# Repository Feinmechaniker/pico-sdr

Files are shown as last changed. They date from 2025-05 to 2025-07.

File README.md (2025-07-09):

This repository holds files relevant to the PiCo Rx project - a design by Jon Dawson 
(see: https://101-things.readthedocs.io/en/latest/breadboard_radio.html ).
I adopted this wonderful idea from Jon to customize the hardware to my liking.

my current circuit diagram
diagram

current circuit board (Top-Side)

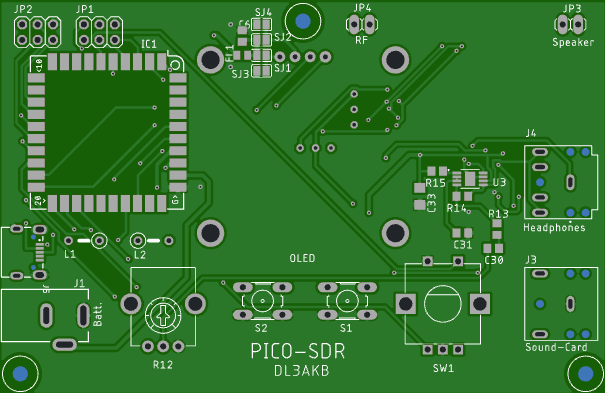
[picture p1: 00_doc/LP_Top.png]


current circuit board (Bottom-Side)

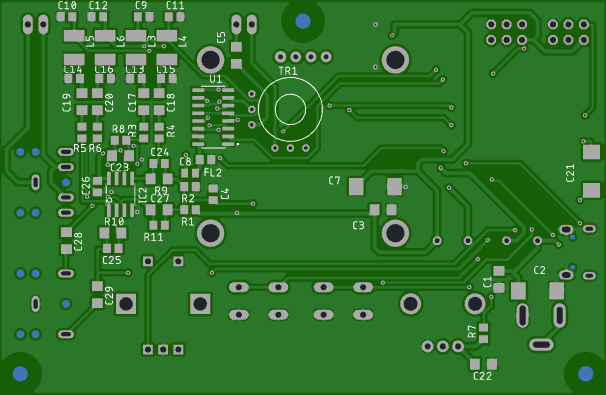
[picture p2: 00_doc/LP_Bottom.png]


current Band-pass filter

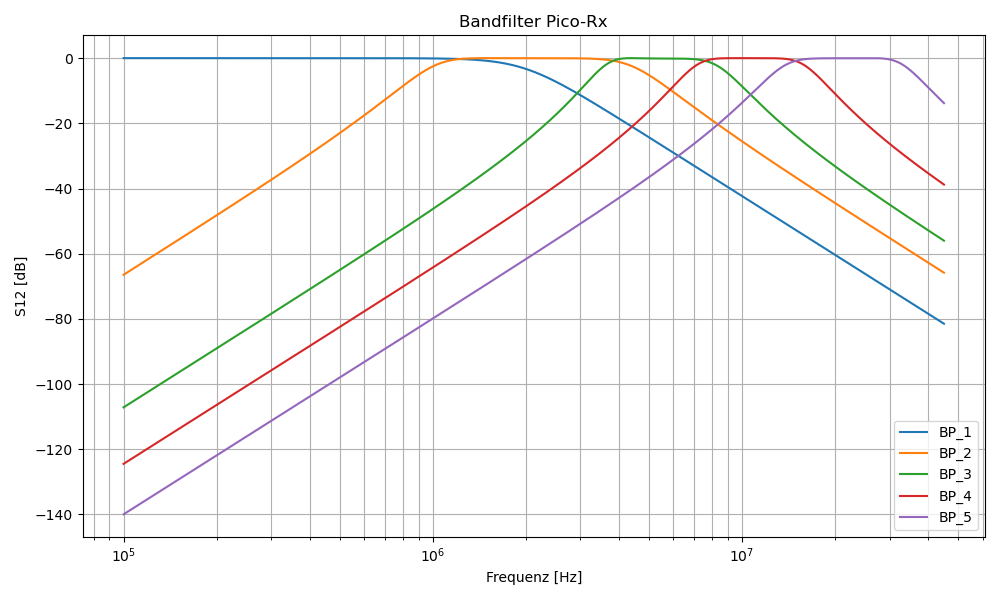
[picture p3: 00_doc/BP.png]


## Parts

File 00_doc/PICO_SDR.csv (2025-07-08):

Part | Value | Device | Package | Description
C1 | 100n | C-EUC1206 | C1206 | CAPACITOR, European symbol
C2 | 100µ | CPOL-EUSMCD | SMC_D | POLARIZED CAPACITOR, European symbol
C3 | 100n | C-EUC1206 | C1206 | CAPACITOR, European symbol
C4 | 2,2µ | C-EUC0805 | C0805 | CAPACITOR, European symbol
C5 | 220n | C-EUC1206 | C1206 | CAPACITOR, European symbol
C6 | 100n | C-EUC0805 | C0805 | CAPACITOR, European symbol
C7 | 100µ | CPOL-EUSMCD | SMC_D | POLARIZED CAPACITOR, European symbol
C8 | 100n | C-EUC0805 | C0805 | CAPACITOR, European symbol
C9 | 10n | C-EUC0805 | C0805 | CAPACITOR, European symbol
C10 | 10n | C-EUC0805 | C0805 | CAPACITOR, European symbol
C11 | 10n | C-EUC0805 | C0805 | CAPACITOR, European symbol
C12 | 10n | C-EUC0805 | C0805 | CAPACITOR, European symbol
C13 | 10n | C-EUC0805 | C0805 | CAPACITOR, European symbol
C14 | 10n | C-EUC0805 | C0805 | CAPACITOR, European symbol
C15 | 10n | C-EUC0805 | C0805 | CAPACITOR, European symbol
C16 | 10n | C-EUC0805 | C0805 | CAPACITOR, European symbol
C17 | 10µ | C-EUC1206 | C1206 | CAPACITOR, European symbol
C18 | 10µ | C-EUC1206 | C1206 | CAPACITOR, European symbol
C19 | 10µ | C-EUC1206 | C1206 | CAPACITOR, European symbol
C20 | 10µ | C-EUC1206 | C1206 | CAPACITOR, European symbol
C21 | 100µ | CPOL-EUSMCD | SMC_D | POLARIZED CAPACITOR, European symbol
C22 | 470n | C-EUC1206 | C1206 | CAPACITOR, European symbol
C23 | 27p | C-EUC1206 | C1206 | CAPACITOR, European symbol
C24 | 27p | C-EUC1206 | C1206 | CAPACITOR, European symbol
C25 | 27p | C-EUC1206 | C1206 | CAPACITOR, European symbol
C26 | 100n | C-EUC0805 | C0805 | CAPACITOR, European symbol
C27 | 27p | C-EUC1206 | C1206 | CAPACITOR, European symbol
C28 | 10µ | C-EUC1206 | C1206 | CAPACITOR, European symbol
C29 | 10µ | C-EUC1206 | C1206 | CAPACITOR, European symbol
C30 | 470n | C-EUC0805 | C0805 | CAPACITOR, European symbol
C31 | 1µ | C-EUC0805 | C0805 | CAPACITOR, European symbol
C33 | 1µ | C-EUC1206 | C1206 | CAPACITOR, European symbol
FL1 | BLM21SP111SH1D | BLM21SP111SH1D | BEADC2012X105N | Check availability
FL2 | BLM21SP111SH1D | BLM21SP111SH1D | BEADC2012X105N | Check availability
IC1 | RP2350 - Stamp | RP2040_STAMPSMD | RP2XXX_STAMP_SMD
IC2 | MCP6022 | OPA2237U | SO08 | Single-Supply Operational Amplifiers
J1 | DCJ0202 | DCJ0202 | DCJ0202 | DC POWER JACK
J3 | FC68131 | FC68131 | CLIFF_FC68131 | Check availability
J4 | FC68133 | FC68133 | CLIFF_FC68133 | Check availability
J5 | 629105150521 | 629105150521 | 629105150521 | WR-COM Micro USB 2.0 SMT Type B Horizontal 5 Contacts High Current
JP1 | Band | PINHD-2X3 | 2X03 | PIN HEADER
JP2 | TFT | PINHD-2X3 | 2X03 | PIN HEADER
JP3 | Speaker | PINHD-1X2 | 1X02 | PIN HEADER
JP4 | RF | PINHD-1X2 | 1X02 | PIN HEADER
L1 | VK200 | L-EU0207/5V | 0207/5V | INDUCTOR, European symbol
L2 | VK200 | L-EU0207/5V | 0207/5V | INDUCTOR, European symbol
L3 | 33µH | L-EUL1812 | L1812 | INDUCTOR, European symbol
L4 | 33µH | L-EUL1812 | L1812 | INDUCTOR, European symbol
L5 | 33µH | L-EUL1812 | L1812 | INDUCTOR, European symbol
L6 | 33µH | L-EUL1812 | L1812 | INDUCTOR, European symbol
OLED1 |  | OLED | 1.3
R1 | 10k | R-EU_R0805 | R0805 | RESISTOR, European symbol
R2 | 10k | R-EU_R0805 | R0805 | RESISTOR, European symbol
R3 | 100 | R-EU_R0805 | R0805 | RESISTOR, European symbol
R4 | 100 | R-EU_R0805 | R0805 | RESISTOR, European symbol
R5 | 100 | R-EU_R0805 | R0805 | RESISTOR, European symbol
R6 | 100 | R-EU_R0805 | R0805 | RESISTOR, European symbol
R7 | 100 | R-EU_R0805 | R0805 | RESISTOR, European symbol
R8 | 100k | R-EU_R0805 | R0805 | RESISTOR, European symbol
R9 | 100k | R-EU_R0805 | R0805 | RESISTOR, European symbol
R10 | 100k | R-EU_R0805 | R0805 | RESISTOR, European symbol
R11 | 100k | R-EU_R0805 | R0805 | RESISTOR, European symbol
R12 | 10k | RK09K1130A6S | RK09K1130A6S | Check availability
R13 | 20k | R-EU_R0805 | R0805 | RESISTOR, European symbol
R14 | 40k | R-EU_R0805 | R0805 | RESISTOR, European symbol
R15 | 20k | R-EU_R0805 | R0805 | RESISTOR, European symbol
S1 |  | 10-XX | B3F-10XX | OMRON SWITCH
S2 |  | 10-XX | B3F-10XX | OMRON SWITCH
SJ1 |  | SJ | SJ | SMD solder JUMPER
SJ2 |  | SJ | SJ | SMD solder JUMPER
SJ3 |  | SJ | SJ | SMD solder JUMPER
SJ4 |  | SJ | SJ | SMD solder JUMPER
SW1 | EC12E_SW | EC12E_SW | ALPS_EC12E_SW | ALPS rotary Encoder EC12E series with switch
TR1 | FT37-43 | FT37-43 | FT37-43
U1 | 74CBTLV3253 | FST3253MX | SOIC127P599X175-16N | Check availability
U3 | MAX9716EUAT | MAX9716EUAT | SOP65P490X110-9N | Check availability

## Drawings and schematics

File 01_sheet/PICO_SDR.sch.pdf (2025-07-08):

A

A

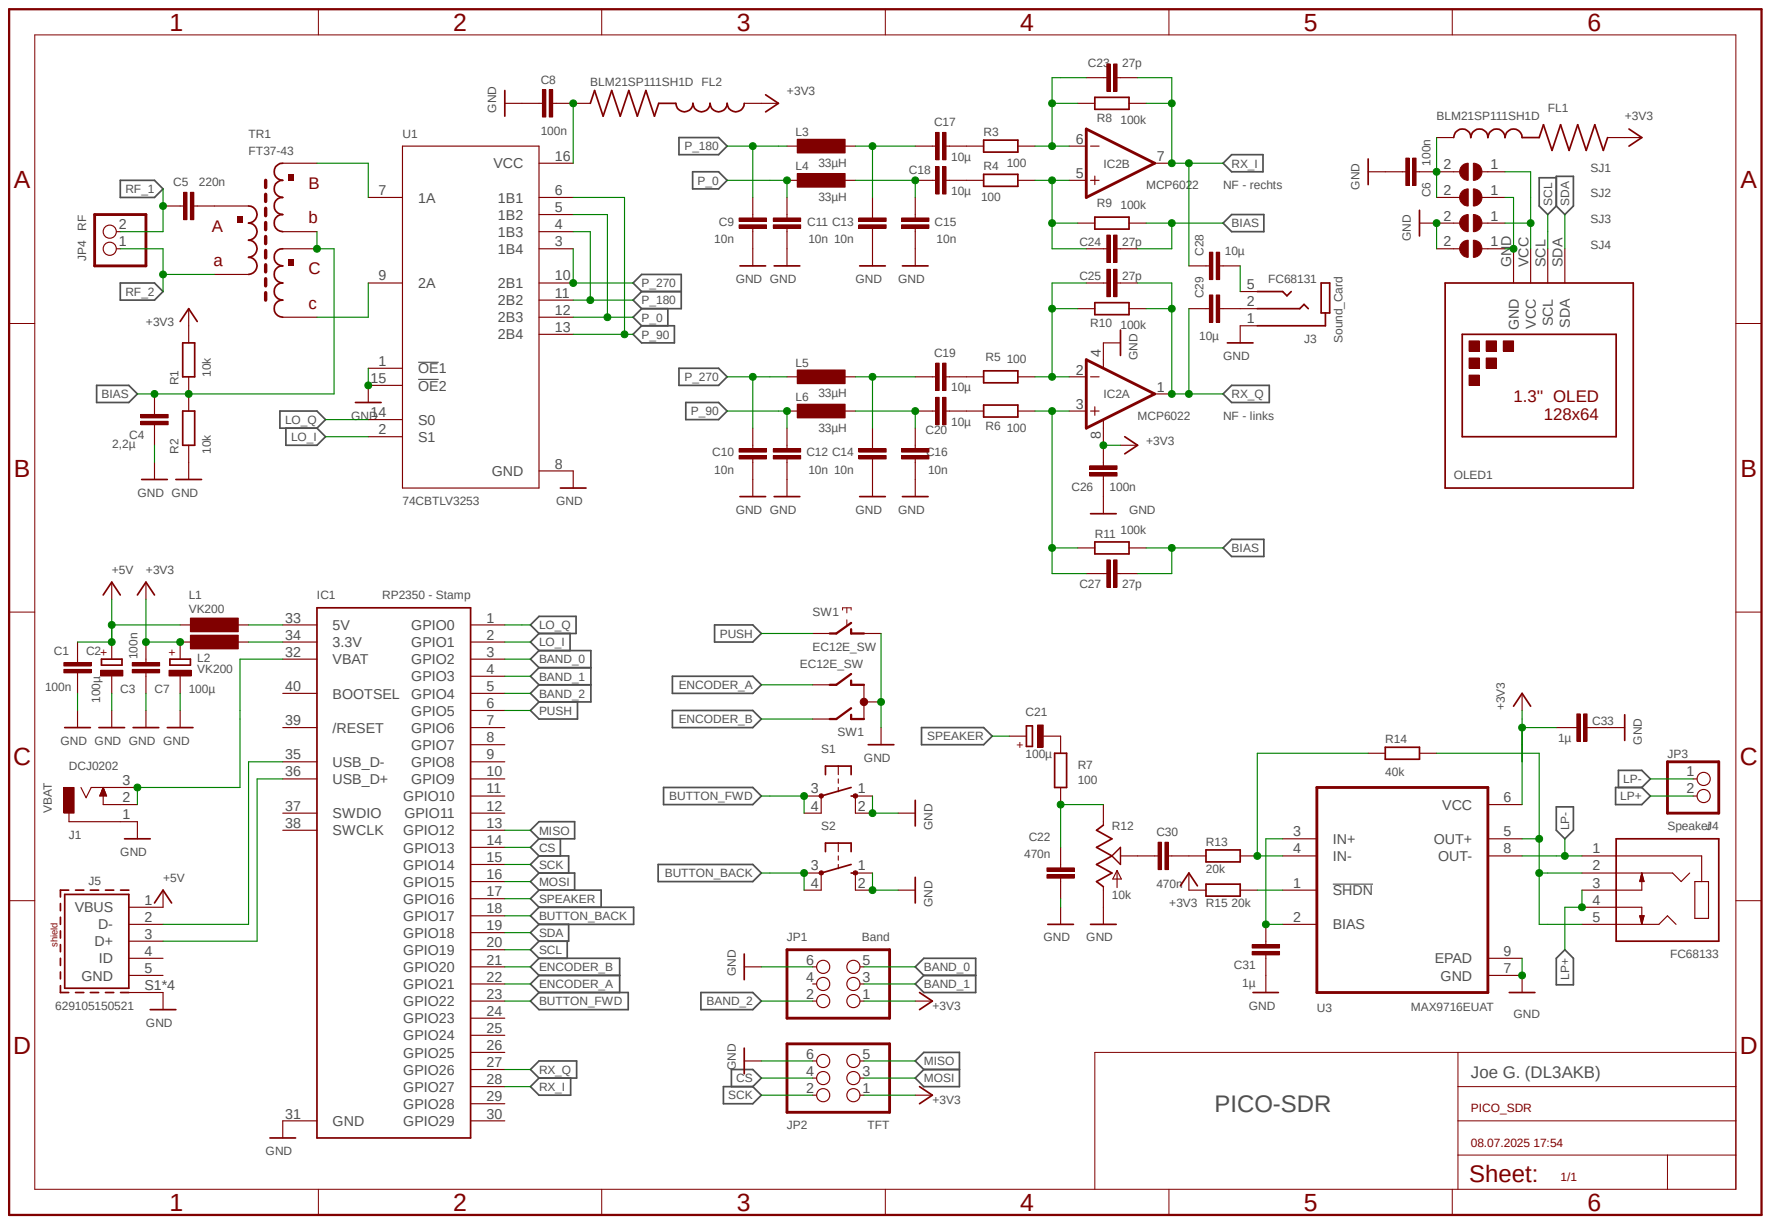
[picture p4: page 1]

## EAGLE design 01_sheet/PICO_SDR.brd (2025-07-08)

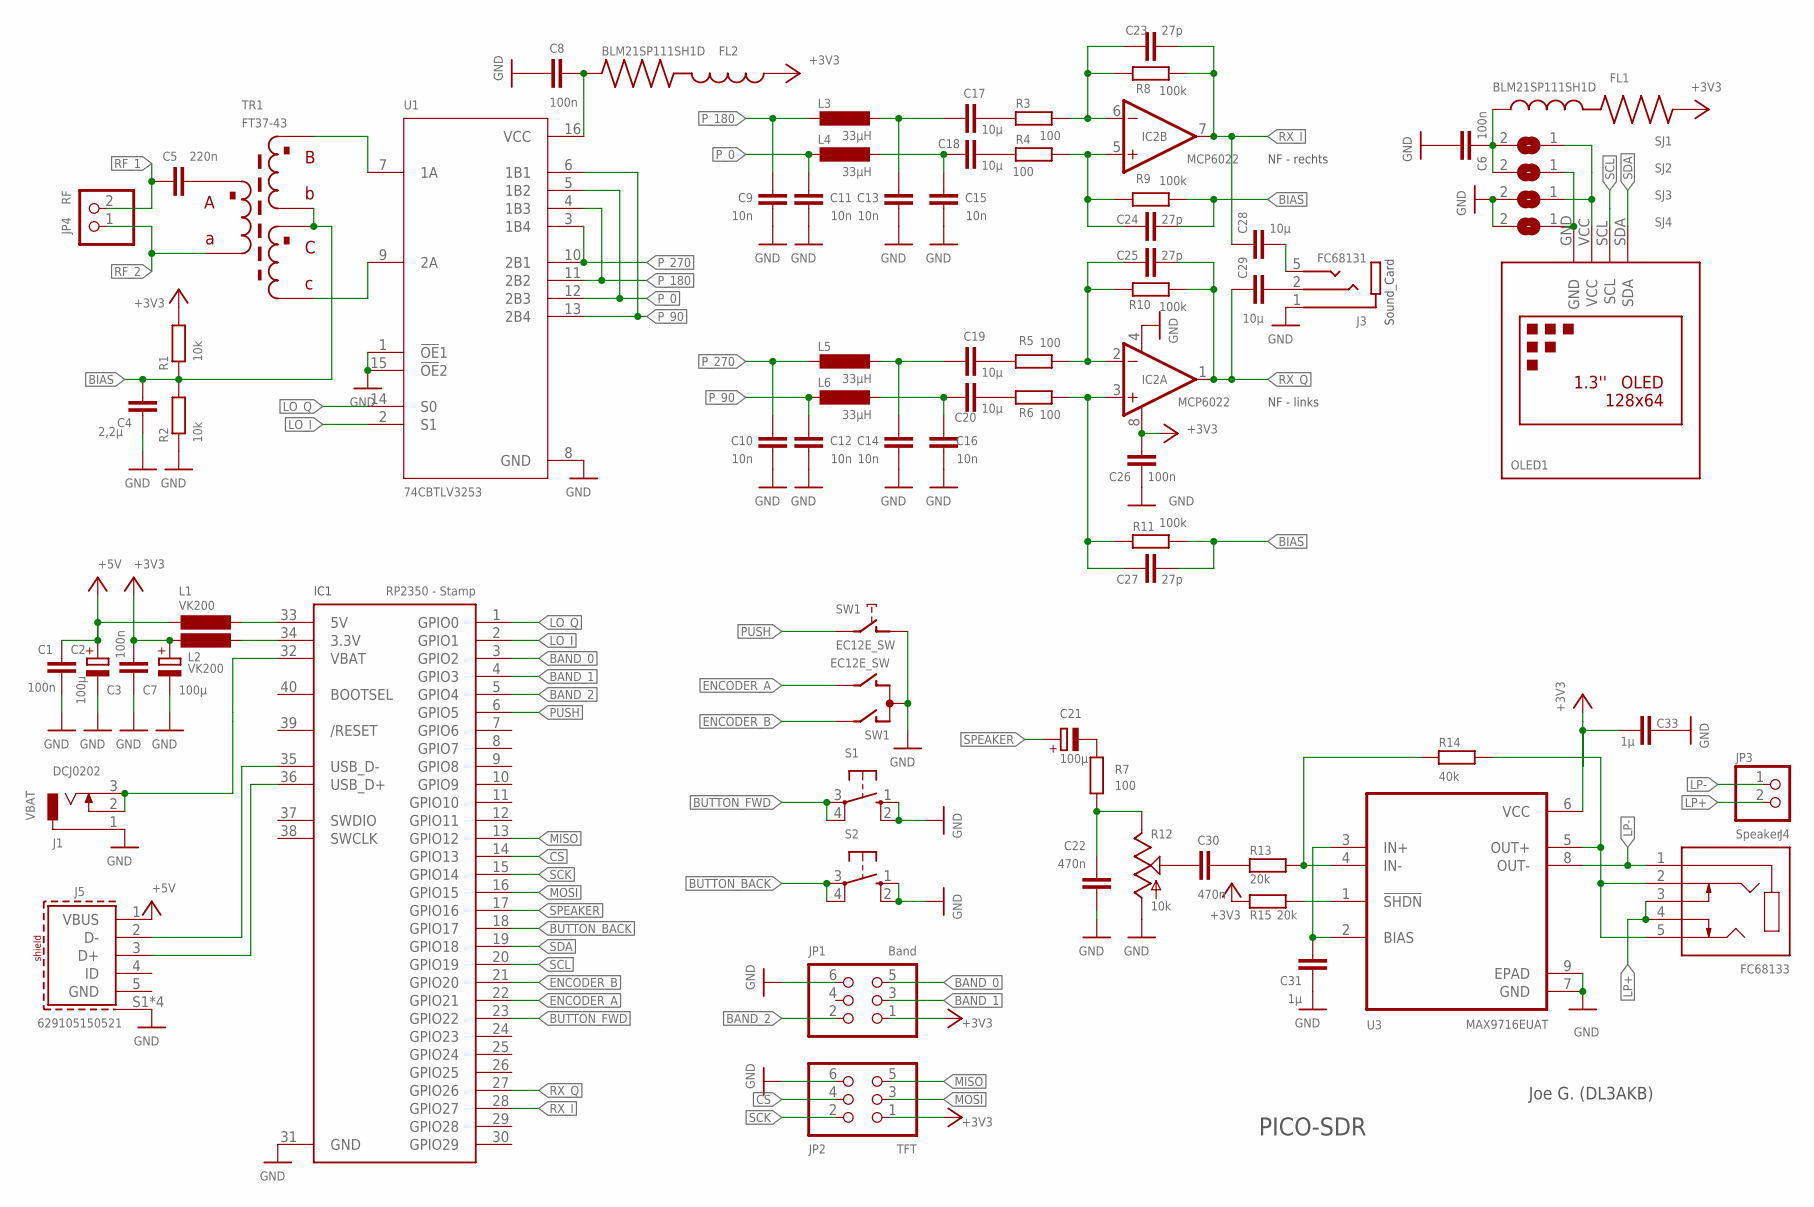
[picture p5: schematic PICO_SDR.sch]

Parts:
C1, C3: 100n; C1206
C2, C7, C21: 100µ; SMC_D
C4: 2,2µ; C0805
C5: 220n; C1206
C6, C8, C26: 100n; C0805
C9, C10, C11, C12, C13, C14, C15, C16: 10n; C0805
C17, C18, C19, C20, C28, C29: 10µ; C1206
C22: 470n; C1206
C23, C24, C25, C27: 27p; C1206
C30: 470n; C0805
C31: 1µ; C0805
C33: 1µ; C1206
FL1, FL2: BLM21SP111SH1D; BEADC2012X105N
IC1: RP2350 - Stamp; RP2XXX_STAMP_SMD
IC2: MCP6022; SO08
J1: DCJ0202
J3: FC68131; CLIFF_FC68131
J4: FC68133; CLIFF_FC68133
J5: 629105150521
JP1: Band; 2X03
JP2: TFT; 2X03
JP3: Speaker; 1X02
JP4: RF; 1X02
L1, L2: VK200; 0207/5V
L3, L4, L5, L6: 33µH; L1812
OLED1: OLED; 1.3
R1, R2: 10k; R0805
R3, R4, R5, R6, R7: 100; R0805
R8, R9, R10, R11: 100k; R0805
R12: 10k; RK09K1130A6S
R13, R15: 20k; R0805
R14: 40k; R0805
S1, S2: 10-XX; B3F-10XX
SJ1, SJ2, SJ3, SJ4: SJ
SW1: EC12E_SW; ALPS_EC12E_SW
TR1: FT37-43
U1: 74CBTLV3253; SOIC127P599X175-16N
U3: MAX9716EUAT; SOP65P490X110-9N

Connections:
+3V3: C3.2, C7.+, C26.2, C33.2, FL1.2, FL2.1, IC2.8 (V+), JP1.1, JP2.1, L2.2, R1.2, R15.2, U3.6 (VCC)
+5V: C1.2, C2.+, J5.1 (VBUS), L1.2
BAND_0: IC1.3 (GPIO2), JP1.5
BAND_1: IC1.4 (GPIO3), JP1.3
BAND_2: IC1.5 (GPIO4), JP1.2
BIAS: C4.2, C24.2, C27.2, R1.1, R2.2, R9.1, R11.1, TR1.P$3, TR1.P$5
BUTTON_BACK: IC1.18 (GPIO17), S2.3, S2.4 (P1)
BUTTON_FWD: IC1.23 (GPIO22), S1.3, S1.4 (P1)
CS: IC1.14 (GPIO13), JP2.4
D+: IC1.36 (USB_D+), J5.3 (D+)
D-: IC1.35 (USB_D-), J5.2 (D-)
ENCODER_A: IC1.22 (GPIO21), SW1.B
ENCODER_B: IC1.21 (GPIO20), SW1.A
GND: C1.1, C2.-, C3.1, C4.1, C6.2, C7.-, C8.2, C9.1, C10.1, C11.1, C12.1, C13.1, C14.1, C15.1, C16.1, C22.1, C26.1, C31.1, C33.1, IC1.31 (GND), IC2.4 (V-), J1.1, J3.1 (SLEEVE), J5.S1 (SHIELD), J5.S2 (SHIELD), J5.S3 (SHIELD), J5.S4 (SHIELD), JP1.6, JP2.6, R2.1, R12.E (3), S1.1 (S), S1.2 (S1), S2.1 (S), S2.2 (S1), SJ3.2, SJ4.2, SW1.C, SW1.D (1), U1.1 (!OE!1), U1.8 (GND), U1.15 (!OE!2), U3.7 (GND), U3.9 (EPAD)
LO_I: IC1.2 (GPIO1), U1.2 (S1)
LO_Q: IC1.1 (GPIO0), U1.14 (S0)
LP+: J4.3, J4.4, JP3.2
LP-: J4.1, JP3.1, U3.8 (OUT-)
MISO: IC1.13 (GPIO12), JP2.5
MOSI: IC1.16 (GPIO15), JP2.3
unnamed: IC1.34 (3.3V), L2.1
unnamed: C21.-, R7.2
unnamed: C16.2, C20.1, L6.2
unnamed: IC1.33 (5V), L1.1
unnamed: TR1.P$6, U1.9 (2A)
unnamed: C19.2, R5.2
unnamed: TR1.P$2, U1.7 (1A)
unnamed: R13.1, R14.2, U3.4 (IN-)
unnamed: C30.2, R12.S (2)
unnamed: C27.1, IC2.3 (+IN), R6.1, R11.2
unnamed: C25.1, IC2.2 (-IN), R5.1, R10.2
unnamed: C18.2, R4.2
unnamed: C23.1, IC2.6 (-IN), R3.1, R8.2
unnamed: C31.2, U3.2 (BIAS), U3.3 (IN+)
unnamed: C17.2, R3.2
unnamed: C24.1, IC2.5 (+IN), R4.1, R9.2
unnamed: C30.1, R13.2
unnamed: C5.2, TR1.P$1
unnamed: C20.2, R6.2
unnamed: C15.2, C18.1, L4.2
unnamed: C28.2, J3.5 (TIP)
unnamed: C29.2, J3.2 (RING)
unnamed: OLED1.GND, SJ2.1, SJ4.1
unnamed: OLED1.VCC, SJ1.1, SJ3.1
unnamed: R15.1, U3.1 (!SHDN)
unnamed: C13.2, C17.1, L3.2
unnamed: C14.2, C19.1, L5.2
unnamed: C6.1, FL1.1, SJ1.2, SJ2.2
unnamed: C8.1, FL2.2, U1.16 (VCC)
NF: C22.2, R7.1, R12.A (1)
OUT_R: J4.2, J4.5, R14.1, U3.5 (OUT+)
PUSH: IC1.6 (GPIO5), SW1.E (2)
P_0: C11.2, L4.1, U1.5 (1B2), U1.12 (2B3)
P_90: C12.2, L6.1, U1.6 (1B1), U1.13 (2B4)
P_180: C9.2, L3.1, U1.4 (1B3), U1.11 (2B2)
P_270: C10.2, L5.1, U1.3 (1B4), U1.10 (2B1)
RF_1: C5.1, JP4.2
RF_2: JP4.1, TR1.P$4
RX_I: C23.2, C28.1, IC1.28 (GPIO27), IC2.7 (OUT), R8.1
RX_Q: C25.2, C29.1, IC1.27 (GPIO26), IC2.1 (OUT), R10.1
SCK: IC1.15 (GPIO14), JP2.2
SCL: IC1.20 (GPIO19), OLED1.SCL
SDA: IC1.19 (GPIO18), OLED1.SDA
SPEAKER: C21.+, IC1.17 (GPIO16)
VBAT: IC1.32 (VBAT), J1.2, J1.3

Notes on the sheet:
Sound_Card
NF - links
NF - rechts
PICO-SDR
Joe G. (DL3AKB)

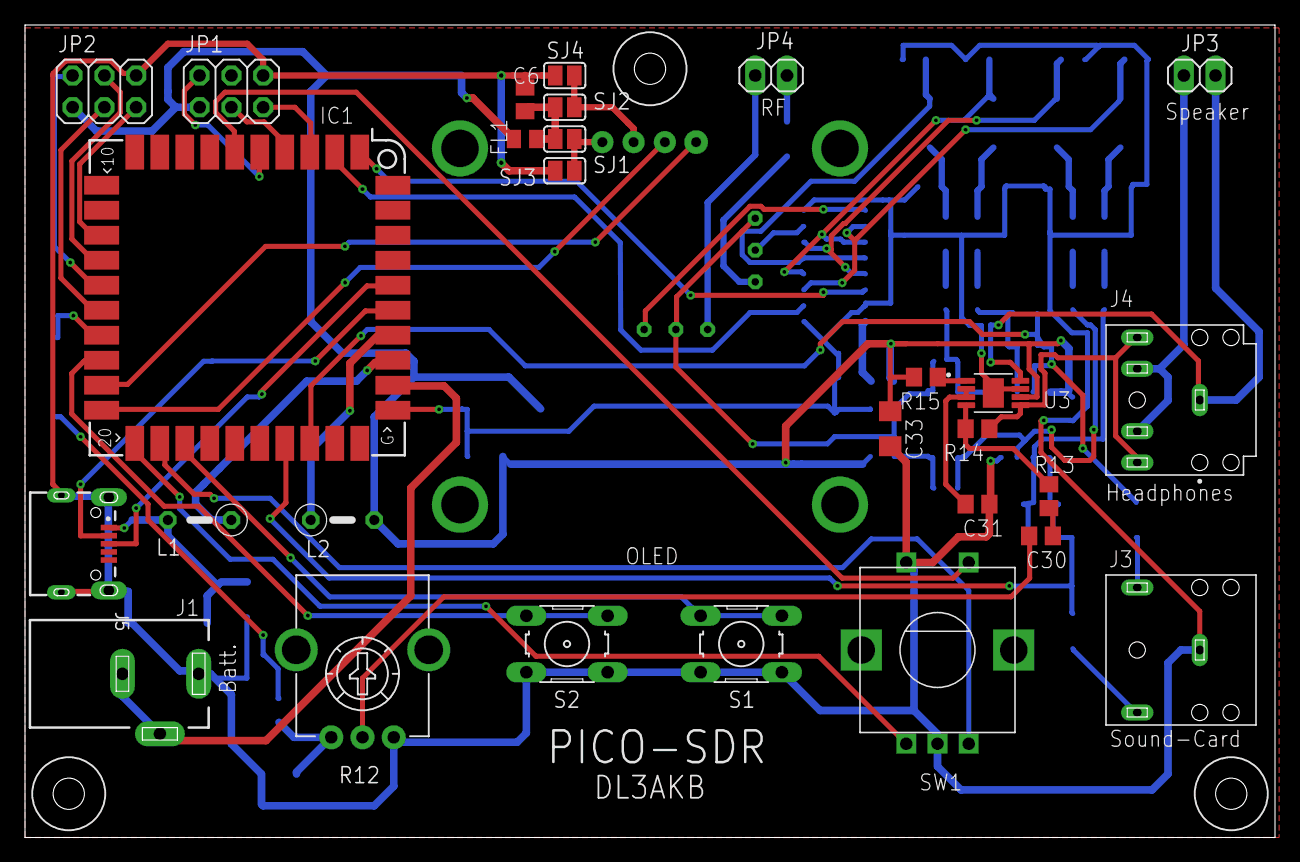
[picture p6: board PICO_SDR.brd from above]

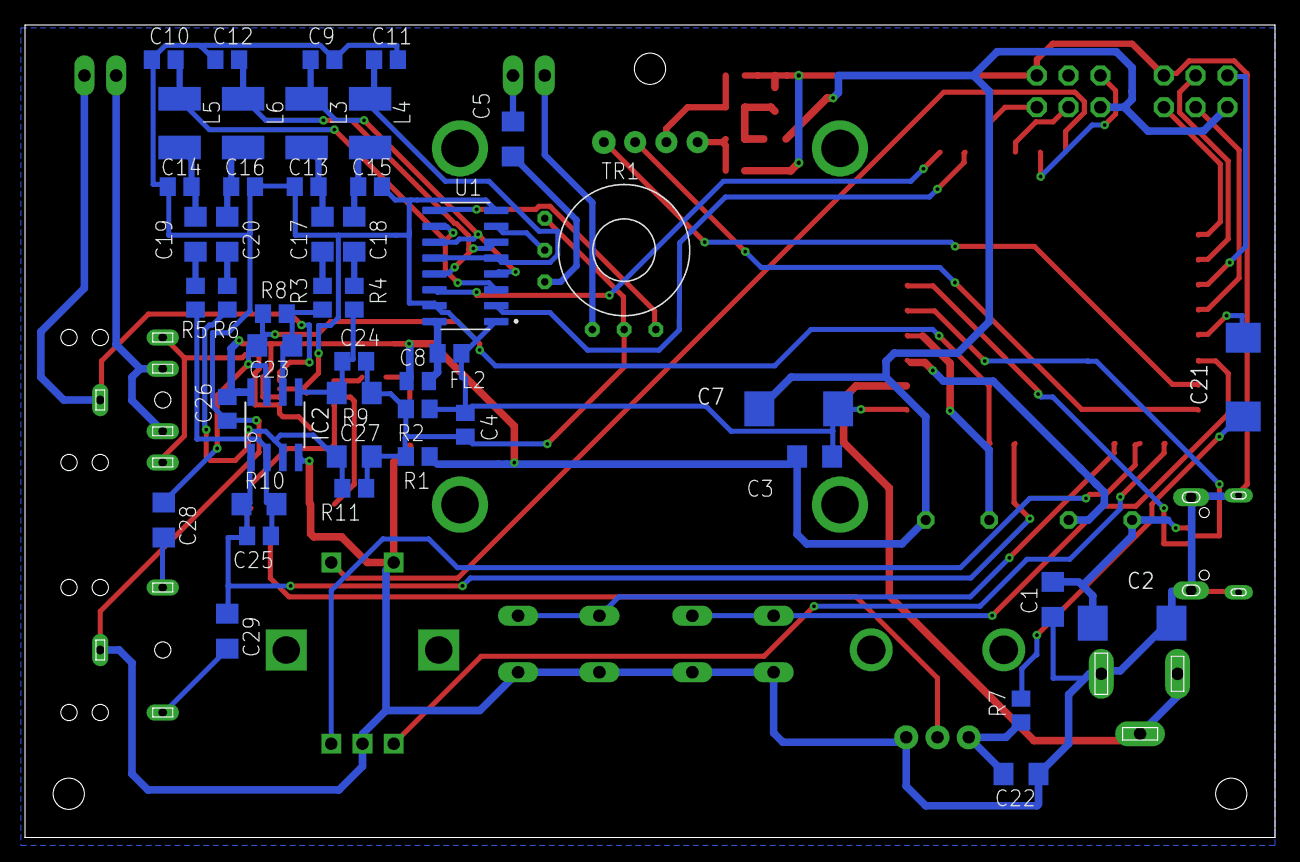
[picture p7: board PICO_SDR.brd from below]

Board: 2 copper layers, 100.0 x 65.0 mm, 79 parts (47 on the bottom side), 65 nets.

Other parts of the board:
U$8, U$9, U$10: DRIL-2,5

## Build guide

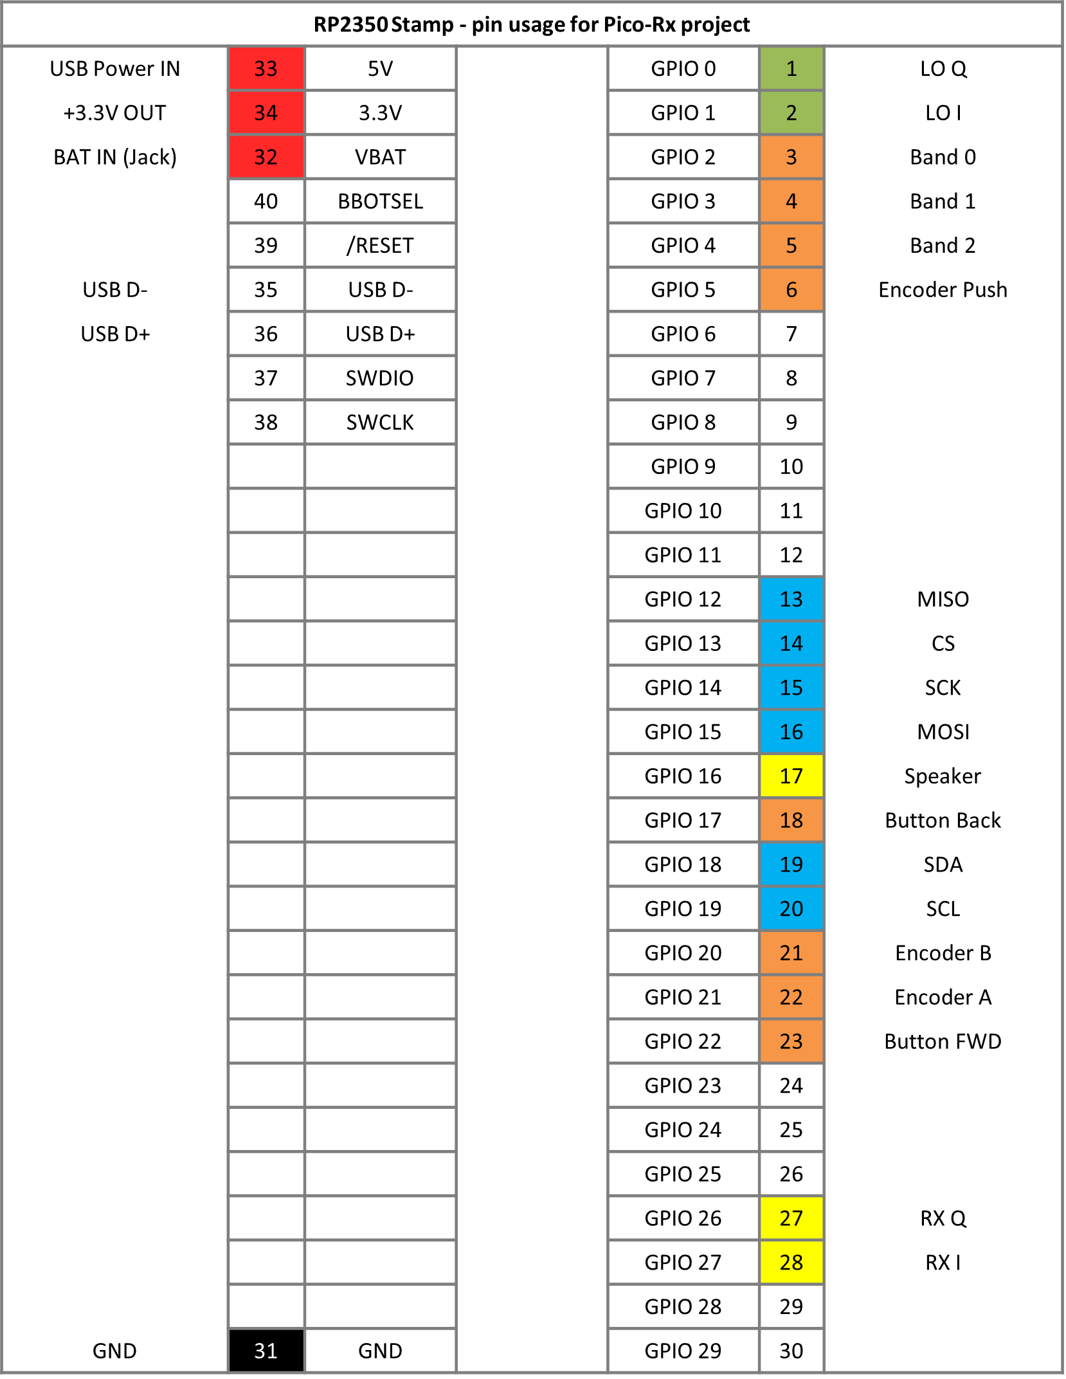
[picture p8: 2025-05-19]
00_doc/RP2350_pin_usage.png

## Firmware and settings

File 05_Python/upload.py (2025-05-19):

# -*- coding: utf-8 -*-
"""
Created on Tue May  6 09:32:57 2025
@author: Jon Dawson, Joe G. (Feinmechaniker)

The original tool comes from Jon Dawson
https://github.com/dawsonjon/PicoRX/tree/master/memory_loader

The tool saves a data block with frequency information on the
Pi-Pico-RX. The frequency information is saved in a CSV file.
A configuration with the name of the CSV file and the COM port can be found 
in the file config.json.

1. Menu -> HW Config
2. HW Config -> USB Upload
3. USB Upload -> Ready for memories
4. start -> upload.py

Program history
05.05.2025    V. 1.0    Start
07.05.2025    V. 1.1    Modes definitions corrected (see rx_definitions.h) 
17.05.2025    V. 1.2    9kHz frequency step for Europe, Asia, Central and South America
"""

__version__ = '1.2'
__author__ = 'Jon Dawson, Joe G. (Feinmechaniker)'


import serial
import struct
import json

def load_config(path="config.json"):
    try:
        with open(path, 'r') as f:
            config = json.load(f)
        dateiname = config.get("filename")
        com_port = config.get("com_port")
        if not dateiname or not com_port:
            raise ValueError("Missing entries in the configuration file.")
        return dateiname, com_port
    except FileNotFoundError:
        print(f"File '{path}' not found.")
    except json.JSONDecodeError:
        print("Error reading the JSON file.")
    except Exception as e:
        print(f"An error has occurred: {e}")
    return None, None


def read_csv(filename):
  channels = []
  with open(filename) as inf:
    for line in inf:
      line = line.strip()
      line = line.split(",")
      line = [i.strip() for i in line]
      channels.append(line)
  return channels

def pack(string):
    return (ord(string[0]) << 24) + (ord(string[1]) << 16) + (ord(string[2]) << 8) + ord(string[3])

def convert_channel_to_hex(channel):
  name, frequency, min_frequency, max_frequency, mode, agc_speed, step = channel

  if len(name) < 16:
    name += " " * (16-len(name))

  modes = { "AM" :0, "AMS":1, "LSB":2, "USB":3, "NFM":4, "CW" :5 }
  agc_speeds = {"FAST": 0, "NORMAL": 1, "SLOW": 2, "VERY SLOW": 3}
  steps = { "10Hz": 0, "50Hz": 1, "100Hz": 2, "1kHz": 3, "5kHz": 4, "9kHz": 5, "10kHz": 6, "12.5kHz": 7, "25kHz": 8, "50kHz": 9, "100kHz": 10,}

  data = [
    int(frequency)&0xffffffff,     #0
    modes[mode],                   #1
    agc_speeds[agc_speed],         #2
    steps[step],                   #3
    int(max_frequency)&0xffffffff, #4
    int(min_frequency)&0xffffffff, #5
    pack(name[0:4]),               #6
    pack(name[4:8]),               #7
    pack(name[8:12]),              #8
    pack(name[12:16]),             #9
    0xffffffff,                    #a
    0xffffffff,                    #b
    0xffffffff,                    #c
    0xffffffff,                    #d
    0xffffffff,                    #e
    0xffffffff,                    #f
  ]
  return data, name.strip()

def read_memory(filename):
  data = read_csv(filename)[1:]
  data = [convert_channel_to_hex(i) for i in data]
  data = data[:512]
  return data
    
filename, port = load_config()
if not filename or not port:
    exit(1)

#send csv file to pico via USB
print("wait for upload...")
buffer = read_memory(filename)
with serial.Serial(port, 12000000, rtscts=1) as ser:

    #clear any data in buffer
    while ser.in_waiting:
      ser.read(ser.in_waiting)

    with open(filename, 'rb') as input_file:
      for index, (channel, name) in enumerate(buffer, start=1):
        for location in channel:
          data = bytes("%x\n" % (location), "utf8")  
          ser.write(bytes("%x\n"%(location), "utf8"))
          ser.readline()
        print(f"send [{index}]: {name}")  
      ser.write(bytes("q\n", "utf8"))
      print("Transmission completed - all channels have been sent successfully.")

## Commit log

2025-05-19 RP2350 pin usage
2025-05-19 memory upload
    [memory.csv]
2025-05-19 EAGLE Board
    [PICO_SDR.brd]
2025-05-20 new version
    [PICO_SDR.brd, PICO_SDR.sch]
2025-07-08 new Version (08.07.25)
    [PICO_SDR.brd, PICO_SDR.sch]
2025-07-09 figure Band-pass filter

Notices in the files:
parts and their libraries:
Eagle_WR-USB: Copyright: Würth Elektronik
